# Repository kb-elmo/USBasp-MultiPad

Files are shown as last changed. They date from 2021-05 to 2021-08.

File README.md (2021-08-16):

# USBasp MultiPad

[][cc-by-sa]
<a href="https://ko-fi.com/kb_elmo">kofibadge</a>

### USBasp flasher for Atmega32a and Atmega328p



### Partslist
Most of the parts in this list are just examples and they can be replaced with any component with the same specs.  
They don't have to be from any specific manufacturer or brand to work on this board.

|Count|Part|Designator|Octopart URL|
|-|-|-|-|
|1|ATmega8-16pu 28-pin DIP|U1|[Atmega8-16pu](https://octopart.com/atmega8-16pu-microchip-77760540)|
|1|28 pin DIP socket (optional but highly recommended)|U1|[TE Connectivity 1-2199298-9](https://octopart.com/1-2199298-9-te+connectivity-39188588)|
|1|2x5 pin header 2.54mm (optional)|AVR|[Würth 61201021621](https://octopart.com/61201021621-w%C3%BCrth+elektronik-8917783)|
|1|USB Type-B receptacle|USB1|[Molex 67068-8000](https://octopart.com/67068-8000-molex-314304)|
|1|500 mA polyfuse|F1|[Bourns MF-R050](https://octopart.com/mf-r050-bourns-19418)|
|1|12 MHz quarz crystal|X1|[CTS ATS120](https://octopart.com/ats120-cts+components-315826)|
|1|16 MHz quarz crystal|X2|[CTS ATS160](https://octopart.com/ats160-cts+components-315830)|
|1|4.7 uF electrolytic capacitor|C1|[Panasonic ECA-1HM4R7I](https://octopart.com/eca-1hm4r7i-panasonic-39478610)|
|2|100 nF ceramic disk capacitor|C2, C3|[Kemet C315C104M5U5TA](https://octopart.com/c315c104m5u5ta-kemet-83288)|
|4|22 pF ceramic disk capacitor|C4, C5, C6, C7|[Kemet C317C220J1G5TA](https://octopart.com/c317c220j1g5ta-kemet-1747641)|
|2|10 kΩ resistor|R2, R5|[Multicomp MF25 10k](https://octopart.com/mf25+10k-multicomp-2697429)|
|2|68 Ω resistor|R3, R4|[Multicomp MF25 68R](https://octopart.com/mf25+68r-multicomp-5364489)|
|3|1.5 kΩ resistor|R1, R6, R7|[Multicomp MF25 1k5](https://octopart.com/mf25+1k5-multicomp-5372506)|
|2|5mm LEDs|ACT, PWR|[Vishay TLHG5400](https://octopart.com/tlhg5400-vishay-39403037)|
|2|3.6 V zener diode (DO-35 BZX55C3V6)|D1, D2|[ON Semiconductor BZX85C3V6](https://octopart.com/bzx85c3v6-on+semiconductor-84409073)|
|1|40-pin ZIF socket (15.24mm row spacing)|U2|3M Textool 240-3345 (or equivalent)|
|1|28-pin ZIF socket (7.62mm row spacing)|U3|3M Textool 228-3341 (or equivalent)|

### PCB preview

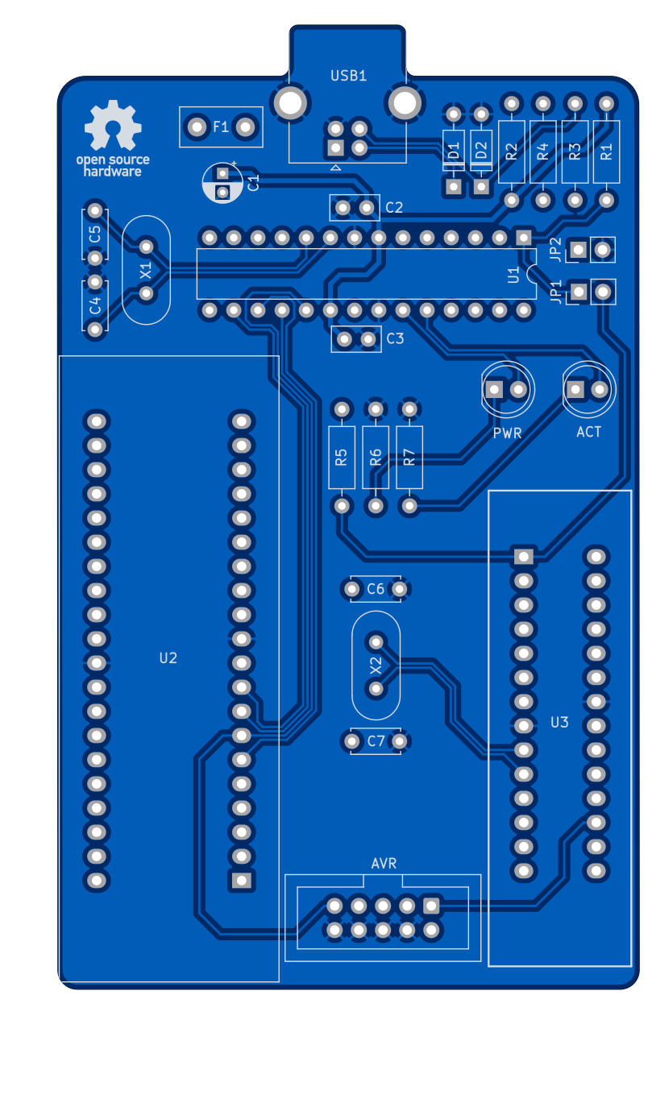
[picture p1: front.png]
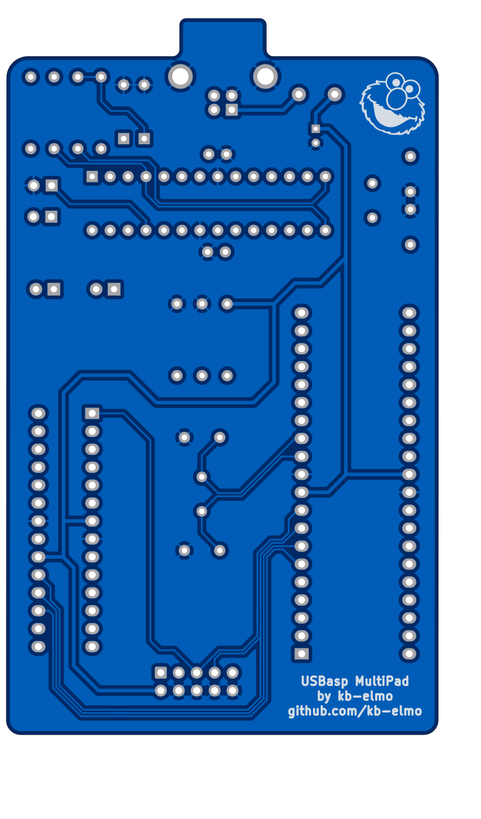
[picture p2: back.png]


This work is licensed under a
[Creative Commons Attribution-ShareAlike 4.0 International License][cc-by-sa].

[][cc-by-sa]

[cc-by-sa]: http://creativecommons.org/licenses/by-sa/4.0/
[cc-by-sa-image]: https://licensebuttons.net/l/by-sa/4.0/88x31.png
[cc-by-sa-shield]: https://img.shields.io/badge/License-CC%20BY--SA%204.0-lightgrey.svg

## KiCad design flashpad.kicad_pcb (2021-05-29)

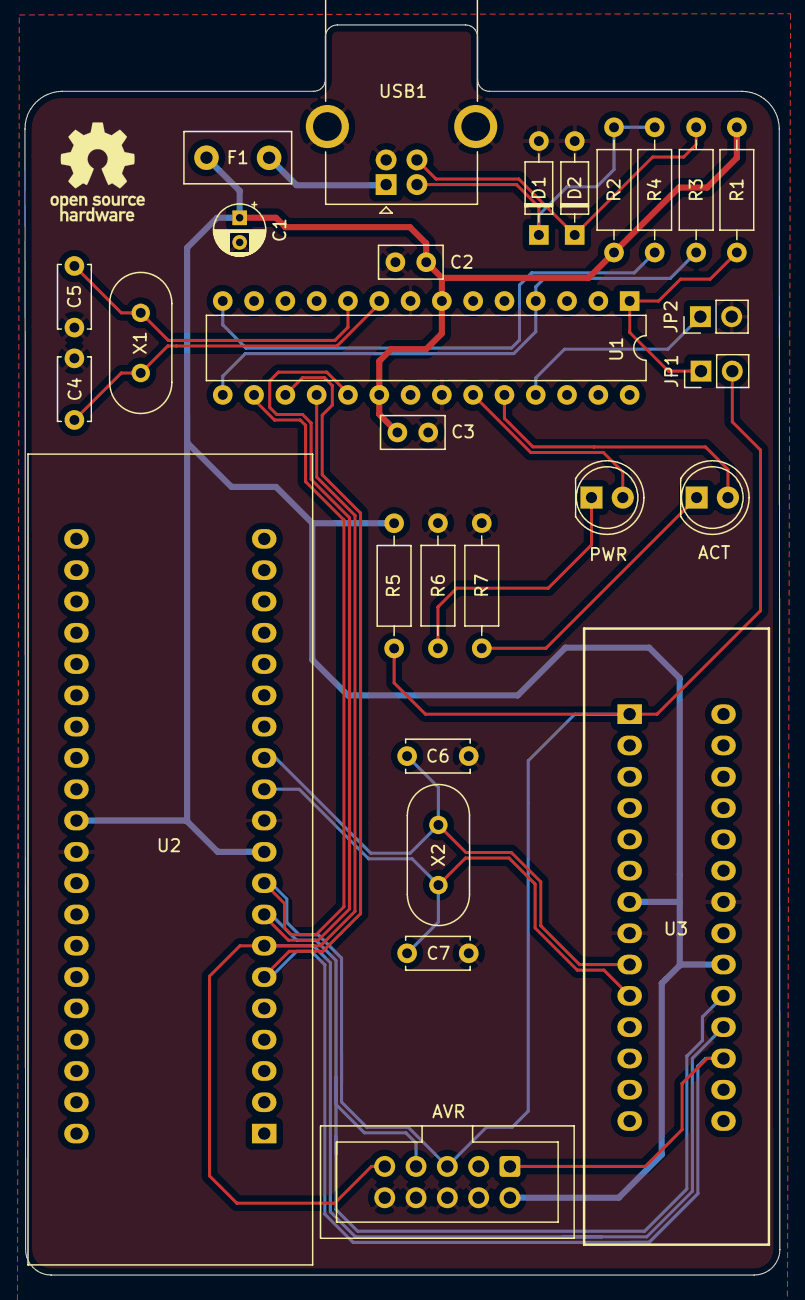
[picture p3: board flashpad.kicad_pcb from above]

Board: 2 copper layers, 61.3 x 101.4 mm, 28 parts (0 on the bottom side), 21 nets.

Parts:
ACT: LED; LED_D5.0mm
AVR: AVR-ISP-10; IDC-Header_2x05_P2.54mm_Vertical
C1: 4.7u; CP_Radial_D4.0mm_P2.00mm
C2, C3: 100n; C_Disc_D5.0mm_W2.5mm_P2.50mm
C4, C5, C6, C7: 22p; C_Disc_D5.0mm_W2.5mm_P5.00mm
D1, D2: 3.6V; D_DO-35_SOD27_P7.62mm_Horizontal
F1: Polyfuse; Fuse_Littelfuse_395Series
JP1: SelfProg; PinHeader_1x02_P2.54mm_Vertical
JP2: SlowSCK; PinHeader_1x02_P2.54mm_Vertical
PWR: LED; LED_D5.0mm
R1, R5: 10k; R_Axial_DIN0207_L6.3mm_D2.5mm_P10.16mm_Horizontal
R2: 1.5k; R_Axial_DIN0207_L6.3mm_D2.5mm_P10.16mm_Horizontal
R3, R4: 68R; R_Axial_DIN0207_L6.3mm_D2.5mm_P10.16mm_Horizontal
R6, R7: 1.5K; R_Axial_DIN0207_L6.3mm_D2.5mm_P10.16mm_Horizontal
U1: ATmega8A-PU; DIP-28_W7.62mm
U2: ATmega32A-PU; socket40dip
U3: ATmega328P-PU; socket28dip
USB1: USB_B; USB_B_OST_USB-B1HSxx_Horizontal
X1: 12Mhz; Crystal_HC49-4H_Vertical
X2: 16Mhz; Crystal_HC49-4H_Vertical

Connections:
+5V: AVR.2, C1.1, C2.1, C3.1, F1.1, R1.1, R2.1, R5.2, U1.7, U1.20, U2.10, U2.30, U3.7, U3.20
D+: R3.2, U1.4, U1.15
D-: R4.2, U1.14
GND: AVR.4, AVR.6, AVR.8, AVR.10, C1.2, C2.2, C3.2, C4.2, C5.2, C6.2, C7.2, D1.2, D2.2, JP2.2, R6.1, R7.1, U1.8, U1.22, U2.11, U2.31, U3.8, U3.22, USB1.4, USB1.5
LED1: PWR.2, U1.23
LED2: ACT.2, U1.24
MISO: AVR.9, U1.18, U2.7, U3.18
MOSI: AVR.1, U1.17, U2.6, U3.17
unnamed: D1.1, R2.2, R4.1, USB1.2
unnamed: D2.1, R3.1, USB1.3
unnamed: JP1.1, R1.2, U1.1
unnamed: JP2.1, U1.25
unnamed: PWR.1, R6.2
unnamed: ACT.1, R7.2
RESET: AVR.5, JP1.2, R5.1, U1.16, U2.9, U3.1
SCK: AVR.7, U1.19, U2.8, U3.19
VCC: F1.2, USB1.1
XTAL1_1: C4.1, U1.9, X1.1
XTAL1_2: C5.1, U1.10, X1.2
XTAL2_1: C6.1, U2.13, U3.9, X2.1
XTAL2_2: C7.1, U2.12, U3.10, X2.2

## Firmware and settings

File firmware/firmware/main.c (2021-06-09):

/*
 * USBasp - USB in-circuit programmer for Atmel AVR controllers
 *
 * Thomas Fischl <tfischl@gmx.de>
 * 2020 fixes and tweaks by Ralph Doncaster (Nerd Ralph)
 *
 * License........: GNU GPL v2 (see Readme.txt)
 * Target.........: ATMega8 at 12 MHz
 * Creation Date..: 2005-02-20
 * Last change....: 2020-11-26
 *
 */

#include <avr/io.h>
#include <avr/interrupt.h>
//#include <avr/pgmspace.h>
#include <avr/wdt.h>

#include "usbasp.h"
#include "usbdrv.h"
#include "isp.h"
#include "clock.h"
#include "tpi.h"
#include "tpi_defs.h"

static uchar replyBuffer[8];

static uchar prog_state = PROG_STATE_IDLE;
uchar prog_sck = USBASP_ISP_SCK_AUTO;

static uchar prog_address_newmode = 0;
static unsigned long prog_address;
static unsigned int prog_nbytes = 0;
static unsigned int prog_pagesize;
static uchar prog_blockflags;
static uchar prog_pagecounter;


/* USBasp default winusb driver for Windows.

   Based on the hard work by Marius Greuel @mariusgreuel ( https://github.com/mariusgreuel/USBasp ).
   This is a non intrusive version, using an unaltered V-USB with no changes in it's usbdrv code.

   To avoid using driver installation (Zadig, libusb) on Windows and use by default
   the winusb default driver for USBasp, we need to use OS feature descriptors. 
   All USB 2.0 devices, when they are enumerated for the first time, Windows asks if 
   there is an OS feature descriptor by sending a specific standard GET_DESCRIPTOR request
   with the format :
   
   --------------------------------------------------------------------------------------------------
   |	bmRequestType	|	bRequest		|	wValue	|	wIndex	|	wLength	|	Data			|
   --------------------------------------------------------------------------------------------------
   |	1000 0000B		|	GET_DESCRIPTOR	|	0x03EE	|	0x0000	|	0x12	|	Returned string	|
   --------------------------------------------------------------------------------------------------
   
   It asks if there is a specific string descriptor at index 0xEE. Because this string 
   descriptor request, is not by default handled by the V-USB, we change the USB_CFG_DESCR_PROPS_UNKNOWN
   to be dynamic (USB_PROP_IS_DYNAMIC). This effectively tell the V-USB that for every 
   unknown string index request to call the usbFunctionDescriptor function.
   
   usbFunctionDescriptor function returns an OS string descriptor using the version 1.00 format 
   which has a fixed length of 18 bytes, with a structure as shown in the following table :

   --------------------------------------------------------------------------
   |	Length	|	Type	|	Signature	|	MS Vendor Code	|	Pad		|
   --------------------------------------------------------------------------
   |	0x12	|	0x03	|	MSFT100		|	unsigned byte	|	0x00	|
   --------------------------------------------------------------------------
   
	Length: An unsigned byte and MUST be set to 0x12.

	Type: An unsigned byte and MUST be set to 0x03.

	Signature: A Unicode string and MUST be set to "MSFT100".

	MS Vendor Code: An unsigned byte, it will be used to retrieve associated feature descriptors.

	Pad: An unsigned byte and MUST be set to 0x00.

    The Signature field contains a Unicode character array that identifies the descriptor as an 
	OS string descriptor and includes the version number. For version 1.00, this array must be set 
	to "MSFT100" (0x4D00 0x5300 0x4600 0x5400 0x3100 0x3000 0x3000).

    The MS VendorCode field is used to retrieve the associated feature descriptors. This code is 
	used as Request field in TS_URB_CONTROL_VENDOR_OR_CLASS_REQUEST section 2.2.9.12.
	
	In usbFunctionSetup we handle the feature request associated to MS Vendor Code we replied earlier 
	and send an Extended Compat ID with the information that we want Windows to load the winusb default driver.

    For More information see

	https://docs.microsoft.com/en-us/windows-hardware/drivers/usbcon/microsoft-defined-usb-descriptors
	https://docs.microsoft.com/en-us/openspecs/windows_protocols/ms-rdpeusb/c2f351f9-84d2-4a1b-9fe3-a6ca195f84d0
	
	
	!!! Notice !!!
	
	"After the operating system requests a Microsoft OS String Descriptor from a device, it creates the following registry key:

	HLKM\SYSTEM\CurrentControlSet\Control\UsbFlags\vvvvpppprrrrr

	The operating system creates a registry entry, named osvc, under this registry key that indicates 
	whether the device supports Microsoft OS Descriptors. If the device does not provide a valid response 
	the first time that the operating system queries it for a Microsoft OS String Descriptor, 
	the operating system will make no further requests for that descriptor."
	
	If your firmware doesn't work please delete the registry key as stated above to retrigger a query from Windows.
	
	i.e. if your firmware has a device version of 0x07, 0x01 then there will be a registry key with the name :
	
	Computer\HKEY_LOCAL_MACHINE\SYSTEM\CurrentControlSet\Control\usbflags\16C005DC0107
	
*/
   
   
/* For Windows OS Descriptors we need to report that we support USB 2.0 */

__flash const char usbDescriptorDevice[18] = {    /* USB device descriptor */
    18,         /* sizeof(usbDescriptorDevice): length of descriptor in bytes */
    USBDESCR_DEVICE,        /* descriptor type */
    0x00, 0x02,             /* USB version supported */
    USB_CFG_DEVICE_CLASS,
    USB_CFG_DEVICE_SUBCLASS,
    0,                      /* protocol */
    8,                      /* max packet size */
    /* the following two casts affect the first byte of the constant only, but
     * that's sufficient to avoid a warning with the default values.
     */
    (char)USB_CFG_VENDOR_ID,/* 2 bytes */
    (char)USB_CFG_DEVICE_ID,/* 2 bytes */
    USB_CFG_DEVICE_VERSION, /* 2 bytes */
    1, /*USB_CFG_DESCR_PROPS_STRING_VENDOR != 0 ? 1 : 0,*/         /* manufacturer string index */
    2, /*USB_CFG_DESCR_PROPS_STRING_PRODUCT != 0 ? 2 : 0, */        /* product string index */
    3, /* USB_CFG_DESCR_PROPS_STRING_SERIAL_NUMBER != 0 ? 3 : 0, */  /* serial number string index */
    1,          /* number of configurations */
};

/* OS Extended Compat ID feature descriptor */

__flash const char OS_EXTENDED_COMPAT_ID[40] = {
	/* Header */
	0x28, 0x00, 0x00, 0x00,									/* OS Extended Compat ID feature descriptor length */
	0x00, 0x01,												/* OS Extended Compat ID version */
	0x04, 0x00,												/* Index */
	0x01,													/* Configurations count */
	0x00, 0x00, 0x00, 0x00, 0x00, 0x00, 0x00,				/* Reserved */
	/* Configuration */
	0x00,													/* First Interface Number */
	0x01,													/* Reserved */
	'W','I','N','U','S','B', 0x00, 0x00,					/* Windows string Compatible ID */
	0x00, 0x00, 0x00, 0x00, 0x00, 0x00, 0x00, 0x00,			/* Windows string SubCompatible ID */ 
	0x00, 0x00, 0x00, 0x00, 0x00, 0x00						/* Reserved */
};

#define MS_VENDOR_CODE 0x5D
__flash const char OS_STRING_DESCRIPTOR[18] = {
  0x12,                                         /* Length: An unsigned byte and MUST be set to 0x12. */  
  /*  https://docs.microsoft.com/en-us/windows-hardware/drivers/network/mb-interface-model-supplement */
  0x03,                                         /* Type: An unsigned byte and MUST be set to 0x03. */
  'M',0,'S',0,'F',0,'T',0,'1',0,'0',0,'0',0,    /* Signature: A Unicode string and MUST be set to "MSFT100". */
  MS_VENDOR_CODE,                               /* MS Vendor Code: An unsigned byte, 
                                                  it will be used to retrieve associated feature descriptors. */
  0x00                                          /* Pad: An unsigned byte and MUST be set to 0x00. */ 
};

usbMsgLen_t usbFunctionDescriptor(struct usbRequest *rq) {

  // DBG1(0xEE, &rq->wValue.bytes[0], 2);

  /* string (3) request at index 0xEE, is an OS string descriptor request */   
  if ((rq->wValue.bytes[1] == 3) && (rq->wValue.bytes[0] == 0xEE)) {

	usbMsgPtr = (usbMsgPtr_t)&OS_STRING_DESCRIPTOR;

	return sizeof(OS_STRING_DESCRIPTOR);

  };

  return 0;

};

uchar usbFunctionSetup(uchar data[8]) {

    uchar len = 0;

    if (data[1] == USBASP_FUNC_CONNECT) {

        /* set SCK speed */
        ispSetSCKOption(prog_sck);

        /* set compatibility mode of address delivering */
        prog_address_newmode = 0;

        ledGreenOn();
        ispConnect();

    } else if (data[1] == USBASP_FUNC_DISCONNECT) {
        ispDisconnect();
        ledGreenOff();

    } else if (data[1] == USBASP_FUNC_TRANSMIT) {
        replyBuffer[0] = ispTransmit(data[2]);
        replyBuffer[1] = ispTransmit(data[3]);
        replyBuffer[2] = ispTransmit(data[4]);
        replyBuffer[3] = ispTransmit(data[5]);
        len = 4;

    } else if (data[1] == USBASP_FUNC_READFLASH) {

        if (!prog_address_newmode)
            prog_address = (data[3] << 8) | data[2];

        prog_nbytes = (data[7] << 8) | data[6];
        prog_state = PROG_STATE_READFLASH;
        len = 0xff; /* multiple in */

    } else if (data[1] == USBASP_FUNC_READEEPROM) {

        if (!prog_address_newmode)
            prog_address = (data[3] << 8) | data[2];

        prog_nbytes = (data[7] << 8) | data[6];
        prog_state = PROG_STATE_READEEPROM;
        len = 0xff; /* multiple in */

    } else if (data[1] == USBASP_FUNC_ENABLEPROG) {
        replyBuffer[0] = ispEnterProgrammingMode();
        len = 1;

    } else if (data[1] == USBASP_FUNC_WRITEFLASH) {

        if (!prog_address_newmode)
            prog_address = (data[3] << 8) | data[2];

        prog_pagesize = data[4];
        prog_blockflags = data[5] & 0x0F;
        prog_pagesize += (((unsigned int) data[5] & 0xF0) << 4);
        if (prog_blockflags & PROG_BLOCKFLAG_FIRST) {
            prog_pagecounter = prog_pagesize;
        }
        prog_nbytes = (data[7] << 8) | data[6];
        prog_state = PROG_STATE_WRITEFLASH;
        len = 0xff; /* multiple out */

    } else if (data[1] == USBASP_FUNC_WRITEEEPROM) {

        if (!prog_address_newmode)
            prog_address = (data[3] << 8) | data[2];

        prog_pagesize = 0;
        prog_blockflags = 0;
        prog_nbytes = (data[7] << 8) | data[6];
        prog_state = PROG_STATE_WRITEEEPROM;
        len = 0xff; /* multiple out */

    } else if (data[1] == USBASP_FUNC_SETLONGADDRESS) {

        /* set new mode of address delivering (ignore address delivered in commands) */
        prog_address_newmode = 1;
        /* set new address */
        prog_address = *((unsigned long*) &data[2]);

    } else if (data[1] == USBASP_FUNC_SETISPSCK) {

        /* set sck option */
        prog_sck = data[2];
        replyBuffer[0] = 0;
        len = 1;

    } else if (data[1] == USBASP_FUNC_TPI_CONNECT) {
        tpi_dly_cnt = data[2] | (data[3] << 8);

        /* RST high */
        ISP_OUT |= (1 << ISP_RST);
        ISP_DDR |= (1 << ISP_RST);

        clockWait(3);

        /* RST low */
        ISP_OUT &= ~(1 << ISP_RST);
        ledGreenOn();

        clockWait(16);
        tpi_init();
    
    } else if (data[1] == USBASP_FUNC_TPI_DISCONNECT) {

        tpi_send_byte(TPI_OP_SSTCS(TPISR));
        tpi_send_byte(0);

        clockWait(10);

        /* pulse RST */
        ISP_OUT |= (1 << ISP_RST);
        clockWait(5);
        ISP_OUT &= ~(1 << ISP_RST);
        clockWait(5);

        /* set all ISP pins inputs */
        ISP_DDR &= ~((1 << ISP_RST) | (1 << ISP_SCK) | (1 << ISP_MOSI));
        /* switch pullups off */
        ISP_OUT &= ~((1 << ISP_RST) | (1 << ISP_SCK) | (1 << ISP_MOSI));

        ledGreenOff();
    
    } else if (data[1] == USBASP_FUNC_TPI_RAWREAD) {
        replyBuffer[0] = tpi_recv_byte();
        len = 1;
    
    } else if (data[1] == USBASP_FUNC_TPI_RAWWRITE) {
        tpi_send_byte(data[2]);
    
    } else if (data[1] == USBASP_FUNC_TPI_READBLOCK) {
        prog_address = (data[3] << 8) | data[2];
        prog_nbytes = (data[7] << 8) | data[6];
        prog_state = PROG_STATE_TPI_READ;
        len = 0xff; /* multiple in */
    
    } else if (data[1] == USBASP_FUNC_TPI_WRITEBLOCK) {
        prog_address = (data[3] << 8) | data[2];
        prog_nbytes = (data[7] << 8) | data[6];
        prog_state = PROG_STATE_TPI_WRITE;
        len = 0xff; /* multiple out */
    
    /* Handle the OS feature request associated with the MS Vendor Code
     we replied earlier in the OS String Descriptor request. See usbFunctionDescriptor. */
    } else if (data[1] == MS_VENDOR_CODE) {
      if (data[4] == 4)
      {
           /* Send the Extended Compat ID OS feature descriptor, 
              requesting to load the default winusb driver for us */
        usbMsgPtr = (usbMsgPtr_t)&OS_EXTENDED_COMPAT_ID;
        usbMsgFlags = USB_FLG_MSGPTR_IS_ROM;
        return sizeof(OS_EXTENDED_COMPAT_ID);
      }
      
      return 0;
	  
    }

    usbMsgPtr = replyBuffer;

    return len;
}

uchar usbFunctionRead(uchar *data, uchar len) {

    uchar i;

    /* check if programmer is in correct read state */
    if ((prog_state != PROG_STATE_READFLASH) && (prog_state
            != PROG_STATE_READEEPROM) && (prog_state != PROG_STATE_TPI_READ)) {
        return 0xff;
    }

    /* fill packet TPI mode */
    if(prog_state == PROG_STATE_TPI_READ)
    {
        tpi_read_block(prog_address, data, len);
        prog_address += len;
        return len;
    }

    /* fill packet ISP mode */
    for (i = 0; i < len; i++) {
        if (prog_state == PROG_STATE_READFLASH) {
            data[i] = ispReadFlash(prog_address);
        } else {
            data[i] = ispReadEEPROM(prog_address);
        }
        prog_address++;
    }

    /* last packet? */
    if (len < 8) {
        prog_state = PROG_STATE_IDLE;
    }

    return len;
}

uchar usbFunctionWrite(uchar *data, uchar len) {

    uchar retVal = 0;
    uchar i;

    /* check if programmer is in correct write state */
    if ((prog_state != PROG_STATE_WRITEFLASH) && (prog_state
            != PROG_STATE_WRITEEEPROM) && (prog_state != PROG_STATE_TPI_WRITE)) {
        return 0xff;
    }

    if (prog_state == PROG_STATE_TPI_WRITE)
    {
        tpi_write_block(prog_address, data, len);
        prog_address += len;
        prog_nbytes -= len;
        if(prog_nbytes <= 0)
        {
            prog_state = PROG_STATE_IDLE;
            return 1;
        }
        return 0;
    }

    for (i = 0; i < len; i++) {

        if (prog_state == PROG_STATE_WRITEFLASH) {
            /* Flash */

            if (prog_pagesize == 0) {
                /* not paged */
                ispWriteFlash(prog_address, data[i], 1);
            } else {
                /* paged */
                ispWriteFlash(prog_address, data[i], 0);
                prog_pagecounter--;
                if (prog_pagecounter == 0) {
                    ispFlushPage(prog_address, data[i]);
                    prog_pagecounter = prog_pagesize;
                }
            }

        } else {
            /* EEPROM */
            ispWriteEEPROM(prog_address, data[i]);
        }

        prog_nbytes--;

        if (prog_nbytes == 0) {
            prog_state = PROG_STATE_IDLE;
            if ((prog_blockflags & PROG_BLOCKFLAG_LAST) && (prog_pagecounter
                    != prog_pagesize)) {

                /* last block and page flush pending, so flush it now */
                ispFlushPage(prog_address, data[i]);
            }

            retVal = 1; // Need to return 1 when no more data is to be received
        }

        prog_address++;
    }

    return retVal;
}

int main(void) {
    /* init timer */
    clockInit();
    
    /* no pullups on USB and ISP pins */
    PORTD = 0;
    PORTB = 0;
    /* all outputs except PD2 = INT0 */
    DDRD = ~(1 << 2);

    /* output SE0 for USB reset */
    DDRB = ~0;
    clockWait(10 / 0.320);              /* 10ms */
    /* all USB and ISP pins inputs to end USB reset */
    DDRB = 0;

    /* all inputs except PC0, PC1 */
    DDRC = 0x03;
    PORTC = 0xfe;

    /* USBasp active */
    ledRedOn();
    ledGreenOff();

    /* main event loop */
    usbInit();
    sei();
    for (;;) {
        usbPoll();
    }
    return 0;
}

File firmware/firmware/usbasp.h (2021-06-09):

/*
 * usbasp.c - part of USBasp
 *
 * Autor..........: Thomas Fischl <tfischl@gmx.de>
 * Description....: Definitions and macros for usbasp
 * Licence........: GNU GPL v2 (see Readme.txt)
 * Creation Date..: 2009-02-28
 * Last change....: 2009-02-28
 */

#ifndef USBASP_H_
#define USBASP_H_

/* USB function call identifiers */
#define USBASP_FUNC_CONNECT     1
#define USBASP_FUNC_DISCONNECT  2
#define USBASP_FUNC_TRANSMIT    3
#define USBASP_FUNC_READFLASH   4
#define USBASP_FUNC_ENABLEPROG  5
#define USBASP_FUNC_WRITEFLASH  6
#define USBASP_FUNC_READEEPROM  7
#define USBASP_FUNC_WRITEEEPROM 8
#define USBASP_FUNC_SETLONGADDRESS 9
#define USBASP_FUNC_SETISPSCK 10
#define USBASP_FUNC_TPI_CONNECT      11
#define USBASP_FUNC_TPI_DISCONNECT   12
#define USBASP_FUNC_TPI_RAWREAD      13
#define USBASP_FUNC_TPI_RAWWRITE     14
#define USBASP_FUNC_TPI_READBLOCK    15
#define USBASP_FUNC_TPI_WRITEBLOCK   16
#define USBASP_FUNC_GETCAPABILITIES 127

/* USBASP capabilities */
#define USBASP_CAP_0_TPI    0x01

/* programming state */
#define PROG_STATE_IDLE         0
#define PROG_STATE_WRITEFLASH   1
#define PROG_STATE_READFLASH    2
#define PROG_STATE_READEEPROM   3
#define PROG_STATE_WRITEEEPROM  4
#define PROG_STATE_TPI_READ     5
#define PROG_STATE_TPI_WRITE    6

/* Block mode flags */
#define PROG_BLOCKFLAG_FIRST    1
#define PROG_BLOCKFLAG_LAST     2

/* ISP SCK speed identifiers */
#define USBASP_ISP_SCK_AUTO   0
#define USBASP_ISP_SCK_0_5    1   /* 500 Hz */
#define USBASP_ISP_SCK_1      2   /*   1 kHz */
#define USBASP_ISP_SCK_2      3   /*   2 kHz */
#define USBASP_ISP_SCK_4      4   /*   4 kHz */
#define USBASP_ISP_SCK_8      5   /*   8 kHz */
#define USBASP_ISP_SCK_16     6   /*  16 kHz */
#define USBASP_ISP_SCK_32     7   /*  32 kHz */
#define USBASP_ISP_SCK_93_75  8   /*  93.75 kHz */
#define USBASP_ISP_SCK_187_5  9   /* 187.5  kHz */
#define USBASP_ISP_SCK_375    10  /* 375 kHz   */
#define USBASP_ISP_SCK_750    11  /* 750 kHz   */
#define USBASP_ISP_SCK_1500   12  /* 1.5 MHz   */
#define USBASP_ISP_SCK_3000   13  /* 3 MHz   */

/* macros for gpio functions */
/* LEDs are active low */
#define ledRedOff()   PORTC &= ~(1 << PC0)
#define ledRedOn()    PORTC |= (1 << PC0)
#define ledGreenOff() PORTC &= ~(1 << PC1)
#define ledGreenOn()  PORTC |= (1 << PC1)

#endif /* USBASP_H_ */

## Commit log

2021-05-20 fix footprints
    [flashpad-B_Cu.gbr, flashpad-B_Mask.gbr, flashpad-B_Paste.gbr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]
2021-05-29 fix prototype issues
    [flashpad-B_Cu.gbr, flashpad-B_Mask.gbr, flashpad-B_Paste.gbr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]
2021-06-09 added firmware
    [USBasp.sch]

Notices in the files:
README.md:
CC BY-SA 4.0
